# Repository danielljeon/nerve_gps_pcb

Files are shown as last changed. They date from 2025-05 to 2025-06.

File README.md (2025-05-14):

# nerve_gps_pcb



GPS module to [`nerve_pcb`](https://github.com/danielljeon/nerve_pcb).

---

<details markdown="1">
  <summary>Table of Contents</summary>

<!-- TOC -->
* [nerve_gps_pcb](#nerve_gps_pcb)
  * [1 Overview](#1-overview)
  * [2 Board Specifications](#2-board-specifications)
    * [2.1 Connectors](#21-connectors)
  * [3 Release Notes](#3-release-notes)
    * [3.1 v0.1.0-alpha](#31-v010-alpha)
    * [3.2 v0.1.0](#32-v010)
<!-- TOC -->

</details>

---

## 1 Overview

| Top | Bottom |
|:---:|:---:|
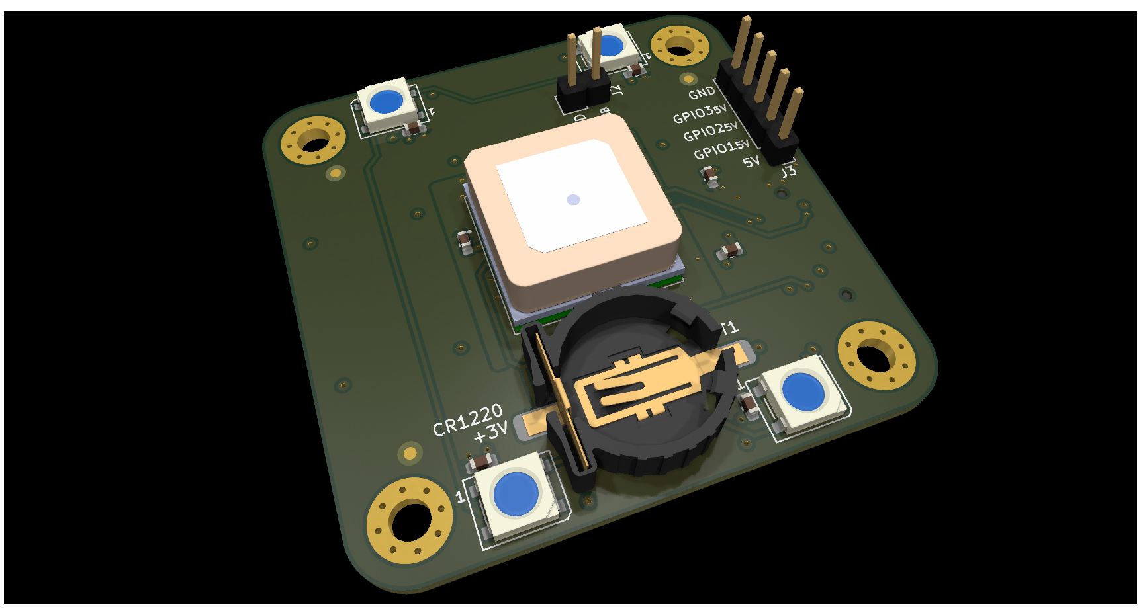
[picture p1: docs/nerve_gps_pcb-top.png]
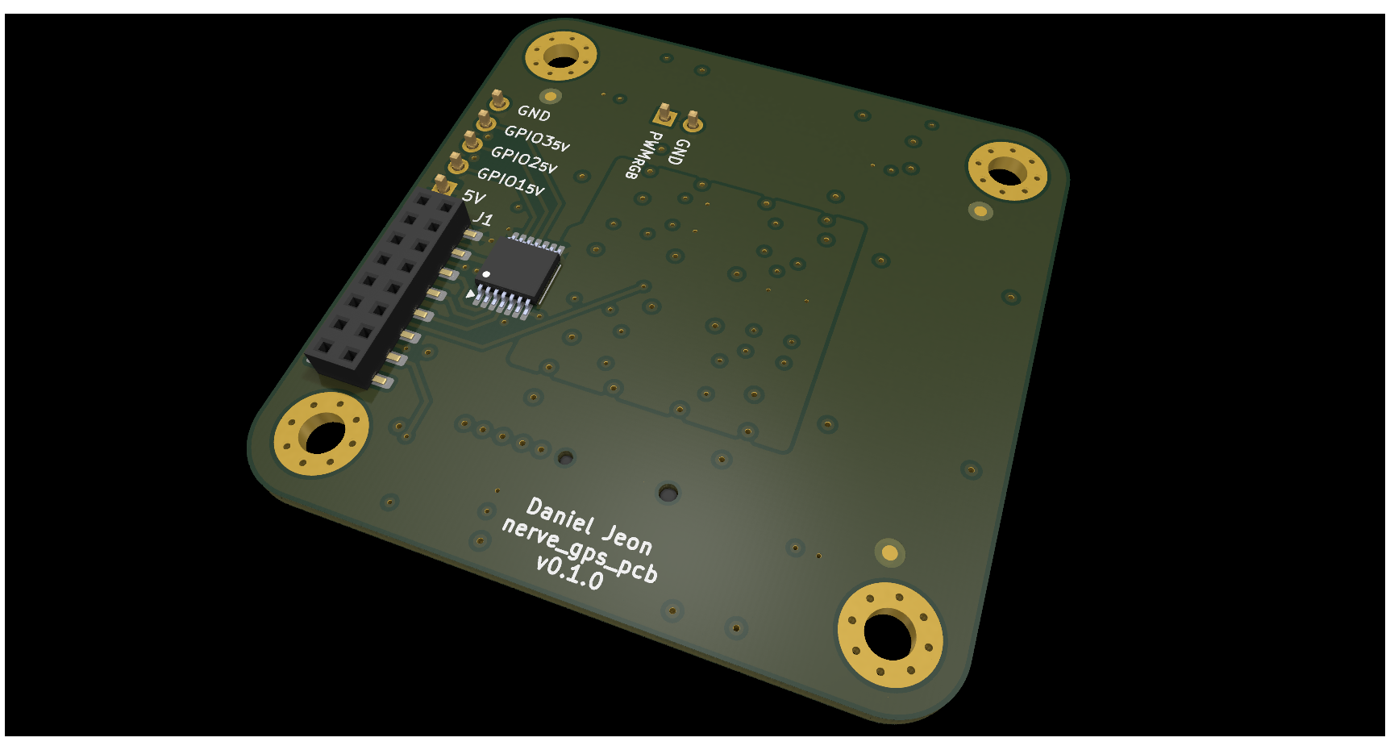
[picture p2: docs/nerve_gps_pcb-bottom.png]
|  |  |

---

## 2 Board Specifications

### 2.1 Connectors

Connectors fixed by hardware (PCB traces or the connector itself).

| Connector | Ref | Description |
|---|:---:|---|
| Bottom side 2x8 board-to-board | J1  | See schematic/layout for details |
| WS2812B PWM breakout | J2  | Pin 1: PWM RGB, Pin 2: Ground |
| 5 V GPIO breakout | J3  | Pin 1: 5 V, Pin 2-4: GPIO1-3 (5 V), Pin 5: Ground |

---

## 3 Release Notes

### 3.1 v0.1.0-alpha

- Pre-release 4-layer board variant.
    - Short-term pre-release board bring-up/testing release.
- Order date: 2025/01/13.

### 3.2 v0.1.0

- Minor changes from the previous `v0.1.0-alpha` pre-release version.
    - Fixed the Double-inverted UART connection issue.

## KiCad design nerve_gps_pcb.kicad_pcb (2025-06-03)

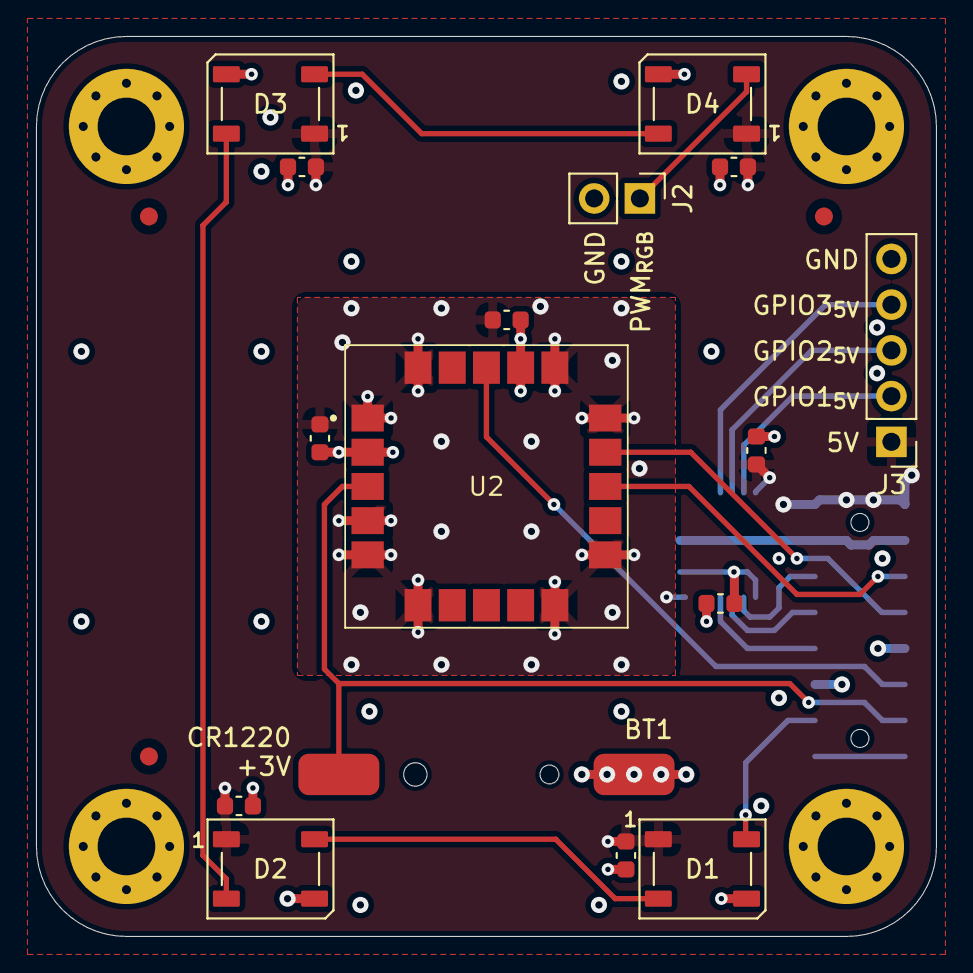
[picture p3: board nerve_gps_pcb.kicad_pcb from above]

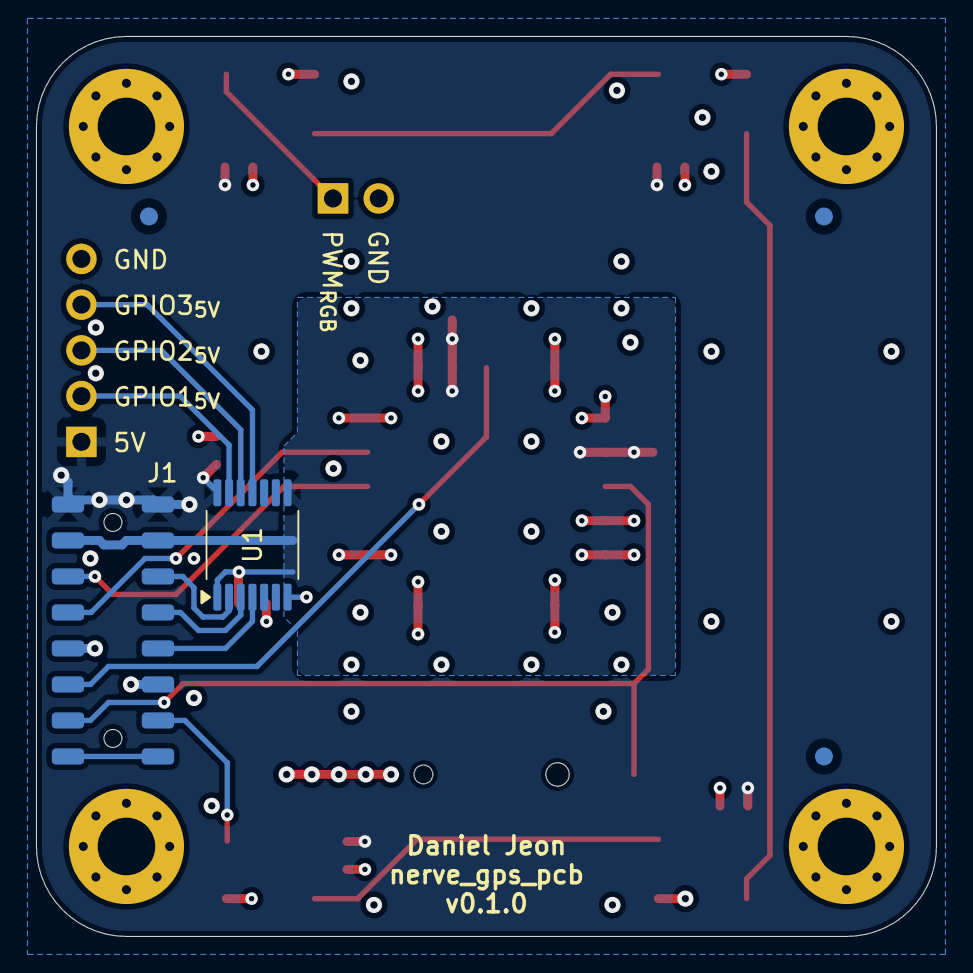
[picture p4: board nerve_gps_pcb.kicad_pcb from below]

Board: 4 copper layers, 50.0 x 50.0 mm, 28 parts (5 on the bottom side), 19 nets.

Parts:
BT1: CR1220; harwin_s8411-45r_cr1220_battery
C1, C2, C3, C4, C5, C6, C7, C8: 100n; C_0603_1608Metric
D1, D2, D3, D4: WS2812B; LED_WS2812B_PLCC4_5.0x5.0mm_P3.2mm
FM1, FM2, FM3, FM4, FM5, FM6: 1mm; Fiducial_1mm_Mask2mm
H1, H2, H3, H4: M3; MountingHole_3.2mm_M3_Pad_Via
J1: BF080-16-A-1-L-C; bf080-16-a-1-l-c
J2: WS2812B; PinHeader_1x02_P2.54mm_Vertical
J3: 5V GPIO Breakout; PinHeader_1x05_P2.54mm_Vertical
U1: TXB0104QPWRQ1; txb0104qpwrq1
U2: SAM-M10Q; ublox_sam

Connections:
+3V3: C1.1, C2.1, C3.1, J1.3, J1.4, U1.1 (V_{CCA}), U1.8 (OE), U2.2 (V_IO), U2.17 (VCC)
+3VBATT: BT1.2, J1.14, U2.3 (V_BCKP)
+5V: C4.1, C5.1, C6.1, C7.1, C8.1, D1.1 (VDD), D2.1 (VDD), D3.1 (VDD), D4.1 (VDD), J1.1, J1.2, J3.1, U1.14 (V_{CCB})
/GPIO_1: J1.5, U1.2 (A1)
/GPIO_1_{5V}: J3.2, U1.13 (B1)
/GPIO_2: J1.7, U1.3 (A2)
/GPIO_2_{5V}: J3.3, U1.12 (B2)
/GPIO_3: J1.9, U1.4 (A3)
/GPIO_3_{5V}: J3.4, U1.11 (B3)
/GPS_NRST: J1.12, U2.18 (RESET_N)
/GPS_UART_RX: J1.8, U2.14 (RXD)
/GPS_UART_TX: J1.6, U2.13 (TXD)
/LED_PWM_{5V}: D1.4 (DIN), J1.13
GND: BT1.1, C1.2, C2.2, C3.2, C4.2, C5.2, C6.2, C7.2, C8.2, D1.3 (VSS), D2.3 (VSS), D3.3 (VSS), D4.3 (VSS), H1.1, H2.1, H3.1, H4.1, J1.10, J1.11, J2.2, J3.5, U1.7 (GND), U2.1 (GND), U2.4 (GND), U2.5 (GND), U2.6 (GND), U2.10 (GND), U2.11 (GND), U2.15 (GND), U2.16 (GND), U2.20 (GND)
unnamed: D1.2 (DOUT), D2.4 (DIN)
unnamed: D2.2 (DOUT), D3.4 (DIN)
unnamed: D3.2 (DOUT), D4.4 (DIN)
unnamed: D4.2 (DOUT), J2.1
unnamed: J1.15, J1.16

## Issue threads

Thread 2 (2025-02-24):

Double-inverted UART connection

danielljeon, 2025-02-24:
# Double-inverted UART connection

The `UART TX` and `UART RX` is inverted twice between controller (nerve_pcb) and this board (nerve_gps_pcb).

1. Once at the schematic connections to the ublox SAM-M10Q schematic:

   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

2. A second time at the board-to-board connectors:

    |                                Controller board: nerve_pcb                                |                                 GPS board: nerve_gps_pcb                                  |
    |:-----------------------------------------------------------------------------------------:|:-----------------------------------------------------------------------------------------:|
    | 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 | 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 |

danielljeon, 2025-02-24:
Fixed with commit 83bcbdb.

**Solution:** Undo inversion at the ublox SAM-M10Q schematic. Routing was fixed near the the board-to-board connector. This seemed to be most logical. All UART TX and RX on this board now match that of the actual GPS component, inversion happens at the board-to-board connector pin mate.

Passed ERC, DRC.

Closed 2025-02-24.

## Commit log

2024-11-18 Add WIP KiCad files
    [nerve_gps_pcb.kicad_pcb, nerve_gps_pcb.kicad_sch]
2024-11-18 Fix board-to-board connector pinout
    [nerve_gps_pcb.kicad_pcb, nerve_gps_pcb.kicad_sch]
2024-11-18 Move PCB dimensions to User Comments layer
    [nerve_gps_pcb.kicad_pcb]
2024-11-18 Pass DRC (ERC previously passed)
    [nerve_gps_pcb.kicad_pcb, nerve_gps_pcb.kicad_sch]
2024-11-19 Combine KiBot BoM directory
2024-11-19 Add stackup PCB notes
    [nerve_gps_pcb.kicad_pcb]
2024-11-19 Update KiBot PCB PDF gen
2024-11-20 Add ground stitching vias and silkscreen cleanup
    [nerve_gps_pcb.kicad_pcb]
2024-11-20 Fix bad vias
    [nerve_gps_pcb.kicad_pcb]
2024-12-03 Add initial README.md and PCB pictures
2024-12-13 Cleanup and update board-to-board connector
    [nerve_gps_pcb.kicad_pcb, nerve_gps_pcb.kicad_sch]
2024-12-13 Add missing connectors library record
2024-12-13 Regenerate PCB
    [nerve_gps_pcb.kicad_pcb]
2025-01-03 Update config.kibot.yaml, cleanup, add fiducials
    [nerve_gps_pcb.kicad_pcb, nerve_gps_pcb.kicad_sch]
2025-01-09 Major cleanup and update component_library
    [nerve_gps_pcb.kicad_pcb, nerve_gps_pcb.kicad_sch]
2025-01-13 Cleanup silkscreen
    [nerve_gps_pcb.kicad_pcb]
2025-02-24 Fix #2
    [nerve_gps_pcb.kicad_pcb, nerve_gps_pcb.kicad_sch]
2025-02-24 Update versioning and docs pictures
    [nerve_gps_pcb.kicad_pcb, nerve_gps_pcb.kicad_sch]
2025-04-03 Update for KiCad 9.0 and component library
    [nerve_gps_pcb.kicad_pcb, nerve_gps_pcb.kicad_sch]
2025-04-03 Fix zone settings and cleanup silkscreen
    [nerve_gps_pcb.kicad_pcb]
2025-04-03 Attempt fix KiBot footprint mismatch warning
    [nerve_gps_pcb.kicad_pcb]
2025-04-03 Attempt fix 2 KiBot footprint mismatch warning
    [nerve_gps_pcb.kicad_pcb]
2025-04-03 Update footprint and symbol library
2025-05-05 Add minor decoupling caps
    [nerve_gps_pcb.kicad_pcb, nerve_gps_pcb.kicad_sch]
2025-05-14 Update README.md for PCB module reference
2025-05-16 Add CR1220 reverse polarity schottky diode
    [nerve_gps_pcb.kicad_pcb, nerve_gps_pcb.kicad_sch]
2025-05-27 Cleanup and fix outer layer non-functional pads
    [nerve_gps_pcb.kicad_pcb]
2025-06-03 Remove CR1220 schottky diode
    [nerve_gps_pcb.kicad_pcb, nerve_gps_pcb.kicad_sch]
2025-06-03 Update config.kibot.yaml for KiCad/Bot 9
2025-10-18 Add board picture
